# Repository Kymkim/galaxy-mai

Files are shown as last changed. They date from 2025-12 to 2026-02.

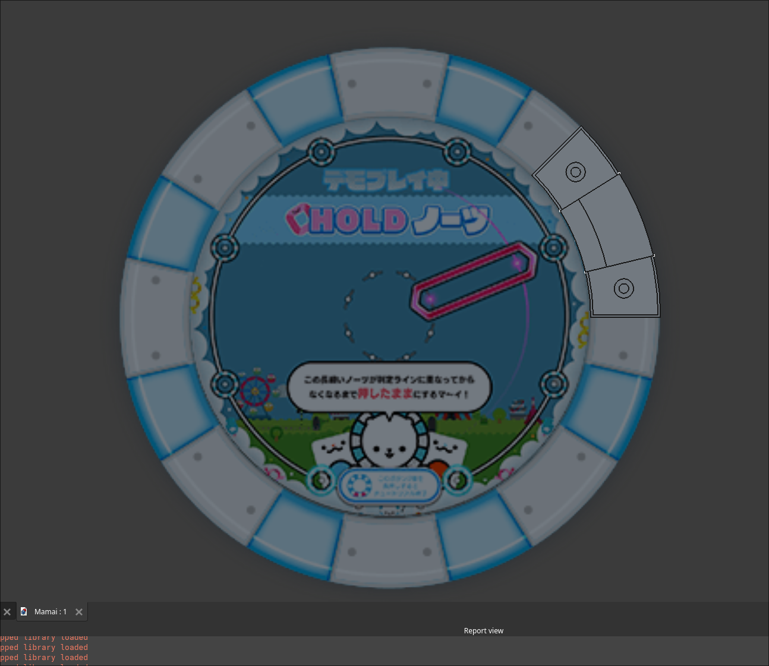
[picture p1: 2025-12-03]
Images/swappy-20251202_193037.png

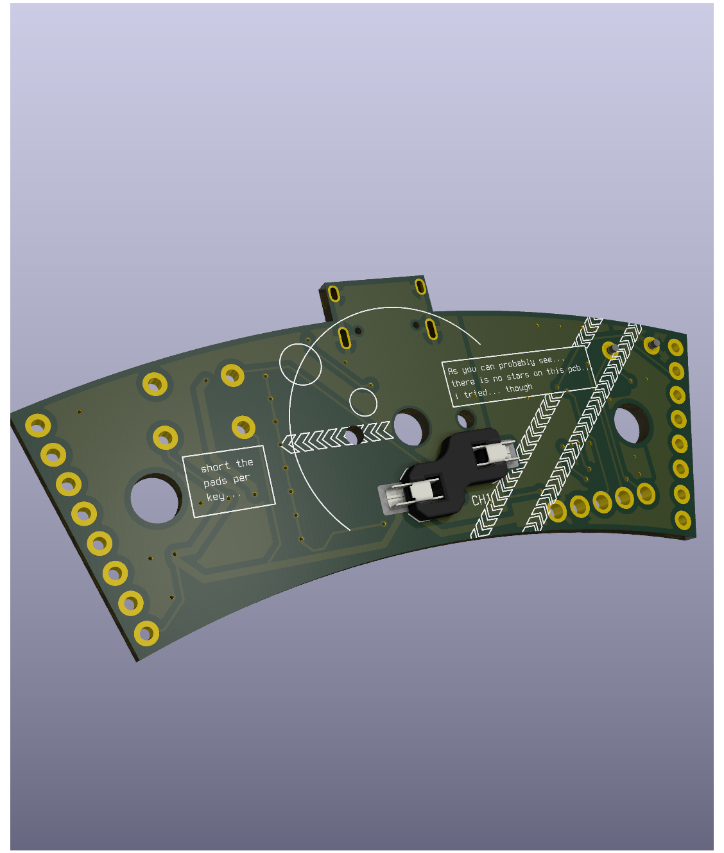
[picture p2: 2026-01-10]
pcb/ss1proto.png

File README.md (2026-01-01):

# galaxy-mai

This project aims to create a AstroDx controller for the Samsung Galaxy Tab

Cooking in progress! Here are some devlogs!

## 01/01/2026: My 3D printer is back!
Few weeks ago I broke my printer so I had to postpone this project for some weeks. I got a new one now so I should be able to hop back into action. Right now I'm in the process of designining the case. Since the design is pretty much constraied by size, I had to draft the case first to get a better idea on how much space I can have once I start putting down the parts in. 

I'm thinking of creating a PCB for this design and some Khail hotswap sockets. They are easy enough to source and should be low profile enough so it looks somewhat proportional to the actual cab. Yes the PCB of course will add up to the overall cost if someone needs to build this instead of just using generic Omron switches - but my reasoning to this is that I want this to be as compact and integrated as possible. 

The schematic and the code of this project is very basic and pretty much just a simple keyboard hid. I have bunch of codes that I have made prior to this project that should let me just reuse the same code and call it the day.

Anyways, I'll keep working on the case and hopefully get something finished and done in one or two weeks

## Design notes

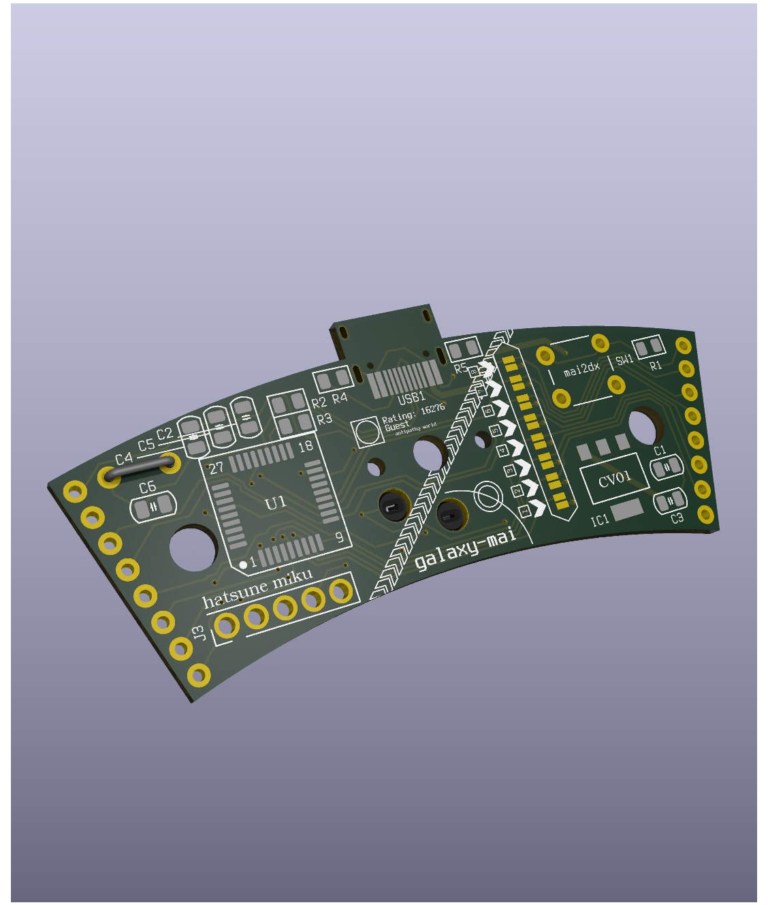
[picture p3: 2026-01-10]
pcb/ss2proto.png

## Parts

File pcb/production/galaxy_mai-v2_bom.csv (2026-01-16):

Designator | Footprint | Quantity | Value | LCSC Part #
C1 | 0805 | 1 | 10uF
C2, C4, C5, C6 | 0805 | 4 | 100uF
C3 | 0805 | 1 | 100nF
CH1 | SW_Hotswap_Kailh_Choc_V1V2 | 1 | choc_v2_SW_HS
IC1 | SOT223 | 1 | LD1117-3.3V-SOT223
JMP_BTN1, JMP_BTN2, JMP_BTN3, JMP_BTN4, JMP_BTN5, JMP_BTN6, JMP_BTN7, JMP_BTN8 | Jumper_2_NO_NoSilk | 8 | ~
R1 | 0805 | 1 | 10k
R2, R3 | 0805 | 2 | 22
R4, R5 | 0805 | 2 | 5.1k
STM32F402K6 | LQFP-32_7x7mm_P0.8mm | 1 | ~
SW1 | SW_PUSH_6mm | 1 | Push_Button
USB1 | HRO-TYPE-C-31-M-12-HandSoldering | 1 | HRO-TYPE-C-31-M-12

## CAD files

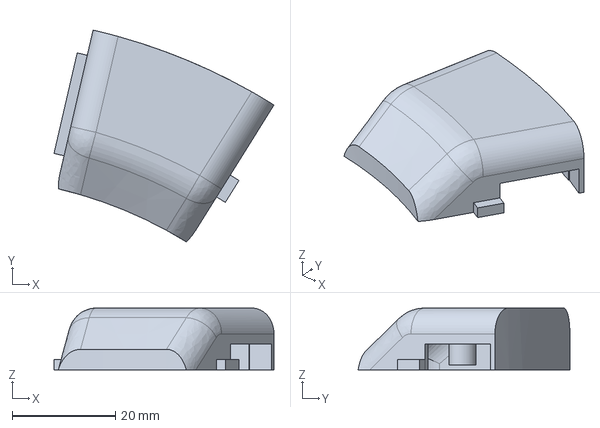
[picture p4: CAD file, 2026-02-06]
3D Parts/Mamai.FCStd
42.6 x 41.1 x 12.0 mm

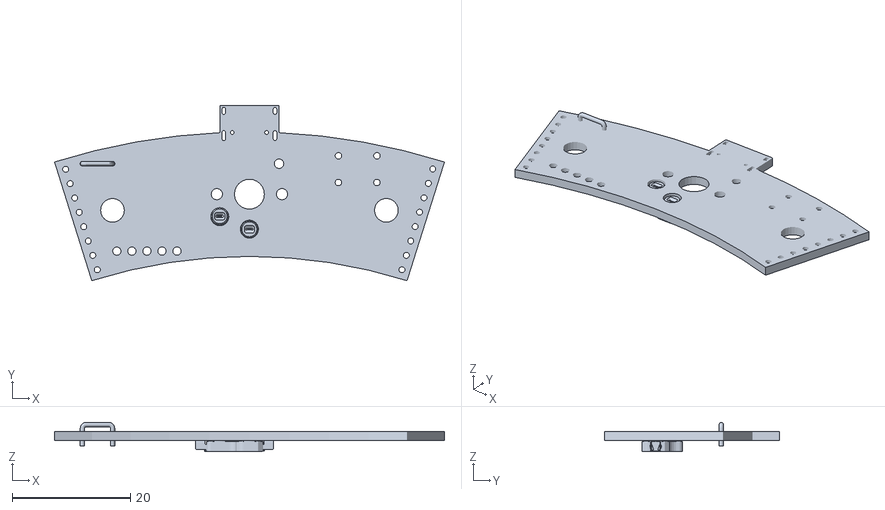
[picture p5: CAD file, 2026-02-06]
pcb/pcb.stl
65.8 x 29.6 x 4.94

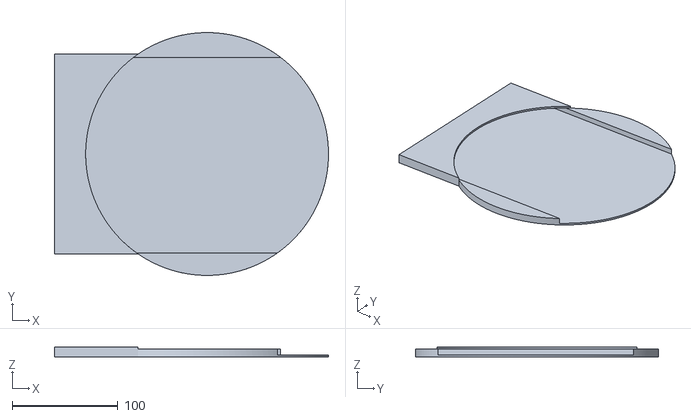
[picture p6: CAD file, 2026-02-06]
3D Parts/Mamai-Case.stl
259.5 x 230.0 x 9.70

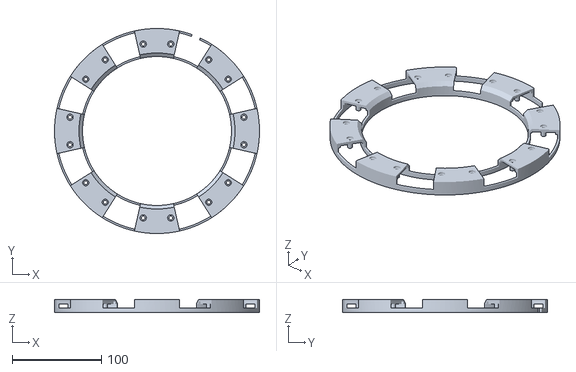
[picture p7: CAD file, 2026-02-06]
3D Parts/Mamai-CaseC.stl
230.0 x 230.0 x 15.0

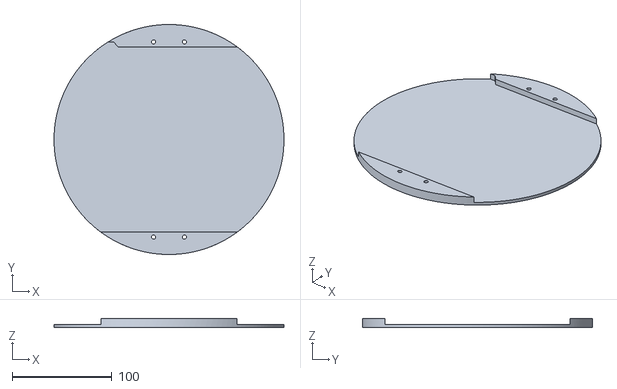
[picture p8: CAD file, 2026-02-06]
3D Parts/Mamai-CaseA.stl
230.0 x 230.0 x 8.70

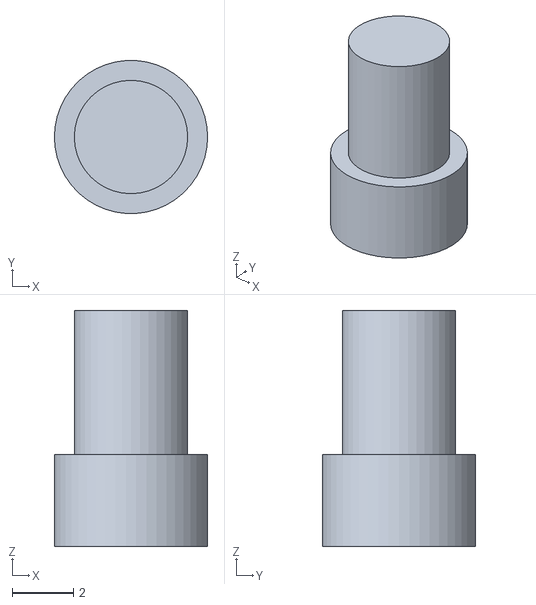
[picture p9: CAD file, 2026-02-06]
3D Parts/Mamai-TestingLockingPin.stl
5.00 x 4.99 x 7.70

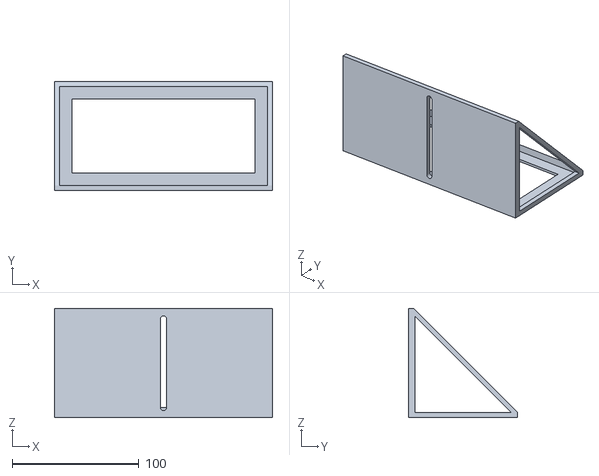
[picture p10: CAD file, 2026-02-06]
3D Parts/Unnamed-Body.stl
172.0 x 86.0 x 86.0

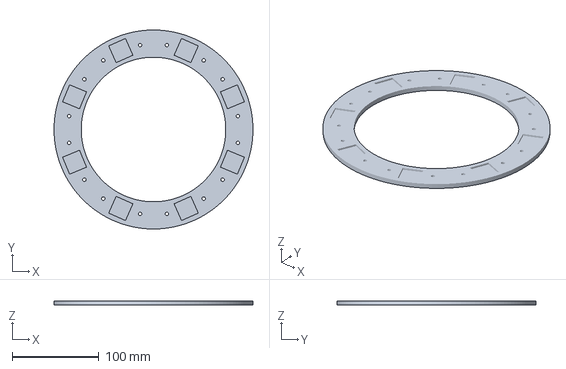
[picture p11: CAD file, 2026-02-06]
3D Parts/Mamai-CaseB.3mf
230.0 x 229.9 x 5.00 mm

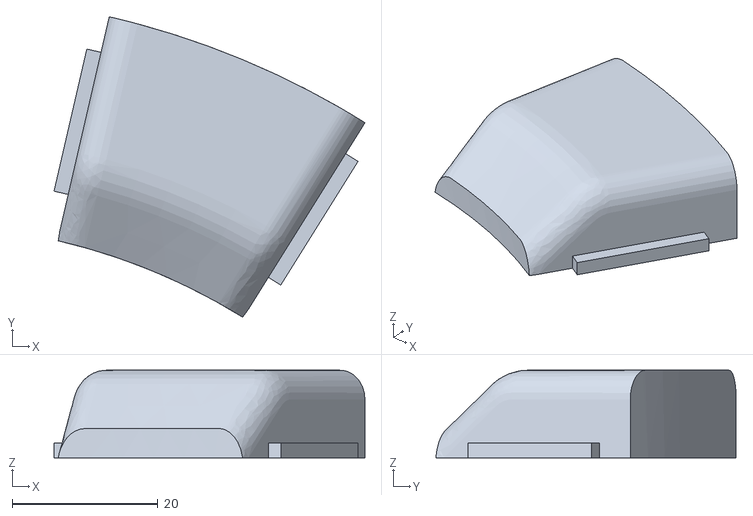
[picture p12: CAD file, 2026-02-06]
3D Parts/Mamai-Button.stl
42.6 x 41.2 x 12.0

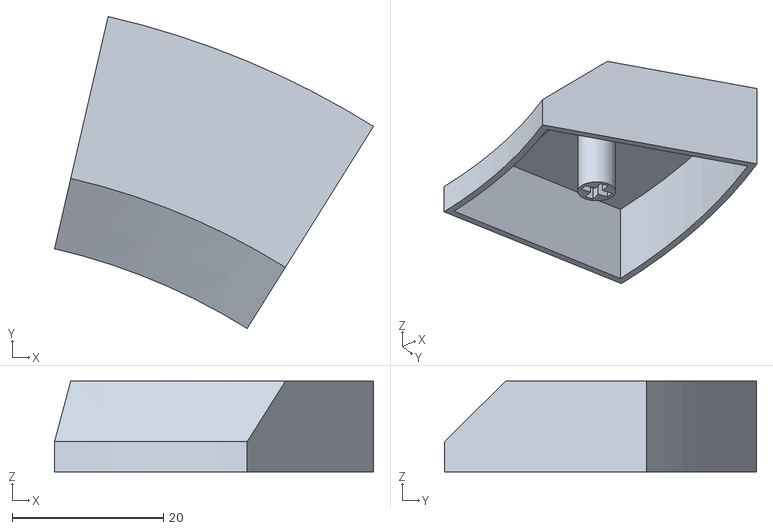
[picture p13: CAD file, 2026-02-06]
3D Parts/Mamai-ButtonPad007.stl
42.2 x 41.2 x 12.0

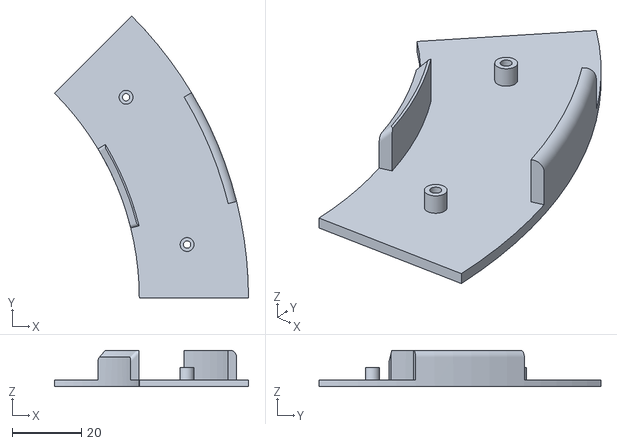
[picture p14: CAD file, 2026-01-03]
3D Parts/Mamai-Body.stl
56.0 x 81.3 x 10.5

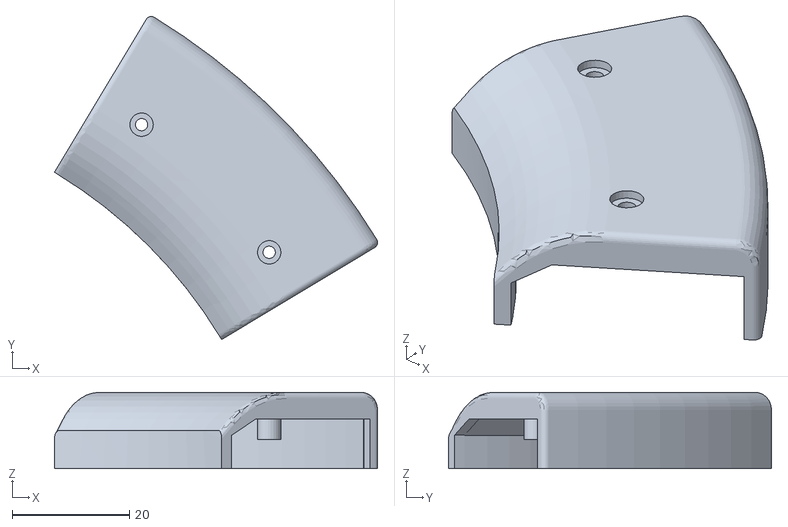
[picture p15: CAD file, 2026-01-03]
3D Parts/Mamai-Joiner.stl
55.2 x 55.2 x 13.0

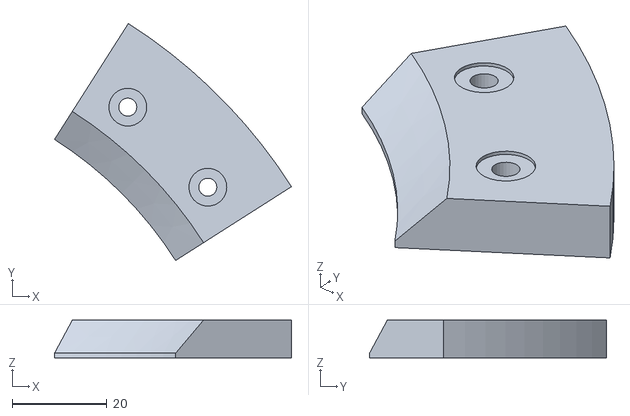
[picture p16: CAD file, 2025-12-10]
3D Parts/Mamai-Body002.stl
50.0 x 50.0 x 8.00

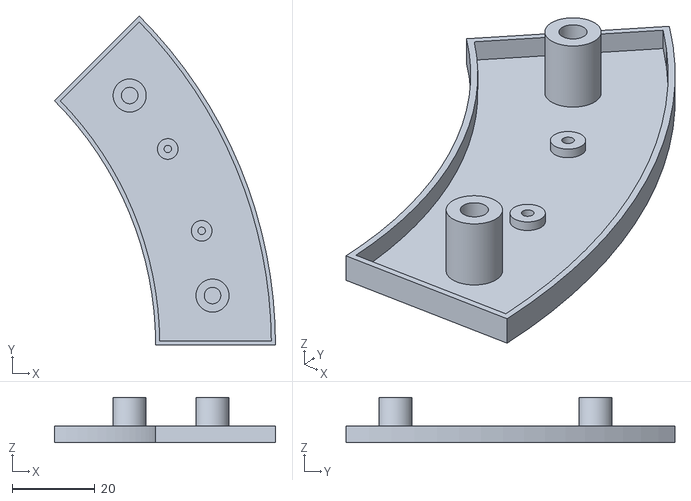
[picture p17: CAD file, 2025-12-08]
3D Parts/baseplate.stl
53.5 x 79.6 x 11.0

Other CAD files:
3D Parts/Mamai-ButtonHoled.stl
3D Parts/Mamai-CaseB.stl
3D Parts/Mamai.3mf
3D Parts/Mamai.stl

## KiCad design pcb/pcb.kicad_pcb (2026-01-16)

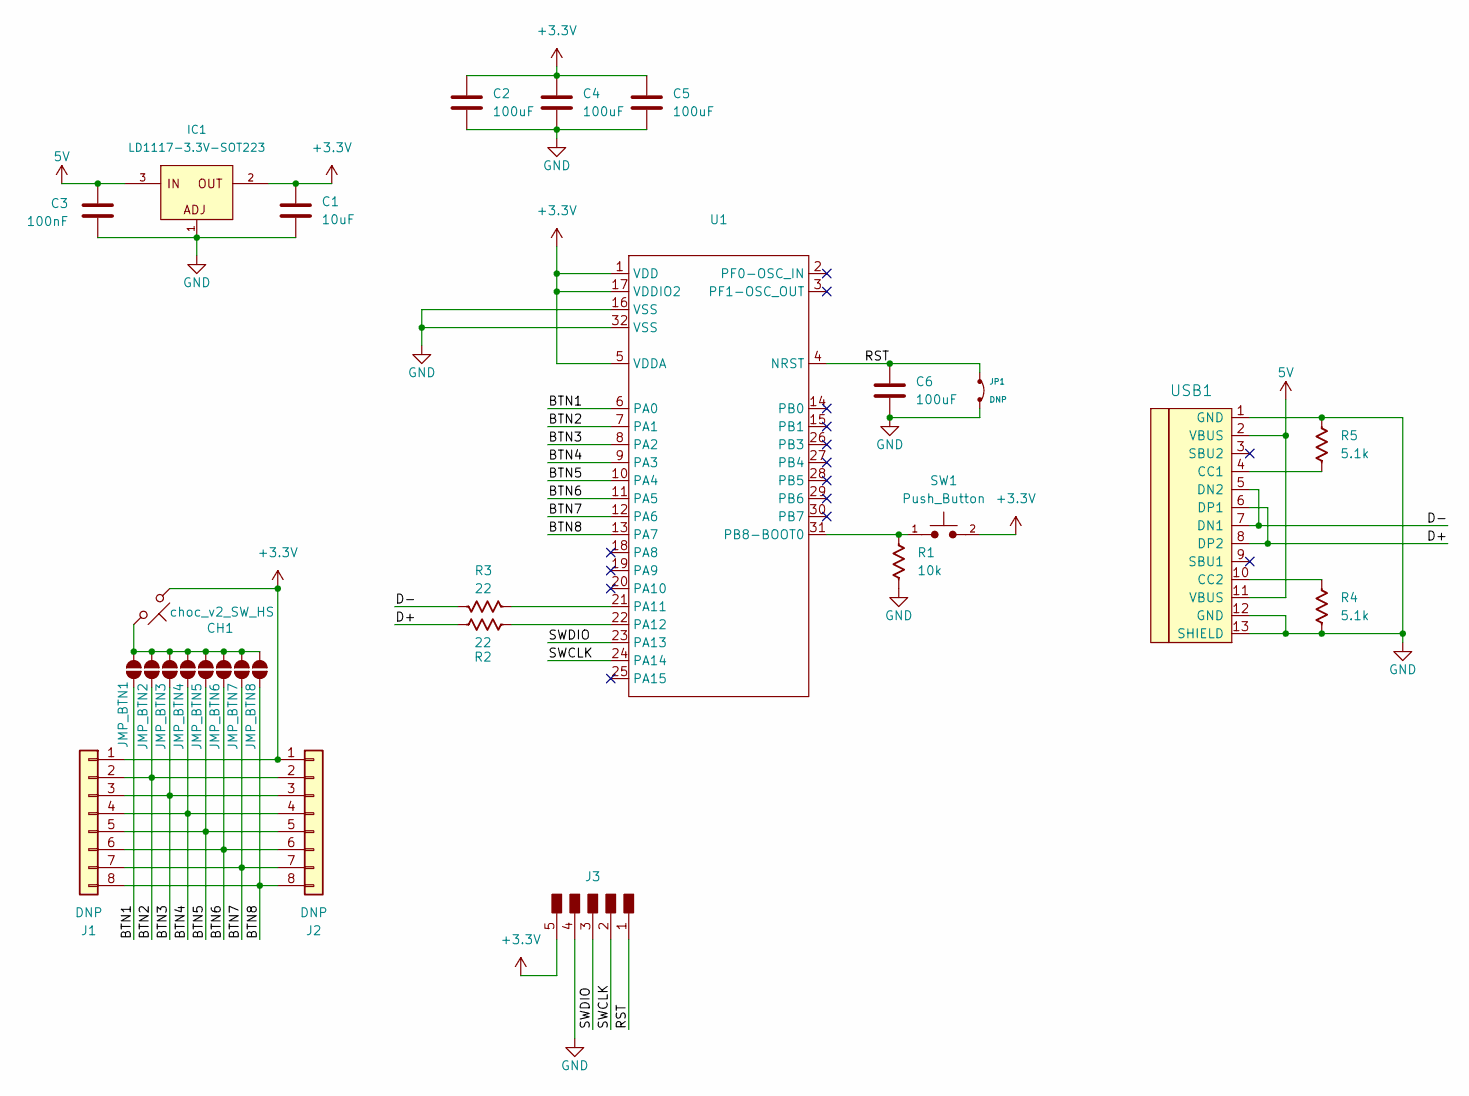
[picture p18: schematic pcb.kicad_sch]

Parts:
C1: 10uF; C_0805_2012Metric
C2, C4, C5, C6: 100uF; C_0805_2012Metric
C3: 100nF; C_0805_2012Metric
CH1: choc_v2_SW_HS; SW_Hotswap_Kailh_Choc_V1V2
IC1: LD1117-3.3V-SOT223; SOT223; Part Number LD1117S33CTR
J1, J2: DNP; 1x08_P2.54mm
J3: DNP; PinHeader_01x05_P2.54mm_Vertical_THT_D1.4mm
JMP_BTN1, JMP_BTN2, JMP_BTN3, JMP_BTN4, JMP_BTN5, JMP_BTN6, JMP_BTN7, JMP_BTN8: Jumper_2_NO_NoSilk
JP1: DNP; JUP_P5.08mm
R1: 10k; R_0805_2012Metric
R2, R3: 22; R_0805_2012Metric
R4, R5: 5.1k; R_0805_2012Metric
SW1: Push_Button; SW_PUSH_6mm
U1: LQFP-32_7x7mm_P0.8mm
USB1: HRO-TYPE-C-31-M-12; HRO-TYPE-C-31-M-12-HandSoldering

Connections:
5V: C3.1, IC1.3 (IN), USB1.2 (VBUS), USB1.11 (VBUS)
+3.3V: C1.2, C2.2, C4.2, C5.2, CH1.2, IC1.2 (OUT), J1.1, J2.1, J3.5, SW1.2, U1.1 (VDD), U1.5 (VDDA), U1.17 (VDDIO2); also elsewhere on the board
/BTN1: JMP_BTN1.2 (B), U1.6 (PA0); also elsewhere on the board
/BTN2: J1.2, J2.2, JMP_BTN2.1 (A), U1.7 (PA1); also elsewhere on the board
/BTN3: J1.3, J2.3, JMP_BTN3.1 (A), U1.8 (PA2); also elsewhere on the board
/BTN4: J1.4, J2.4, JMP_BTN4.1 (A), U1.9 (PA3); also elsewhere on the board
/BTN5: J1.5, J2.5, JMP_BTN5.1 (A), U1.10 (PA4); also elsewhere on the board
/BTN6: J1.6, J2.6, JMP_BTN6.1 (A), U1.11 (PA5); also elsewhere on the board
/BTN7: J1.7, J2.7, JMP_BTN7.1 (A), U1.12 (PA6); also elsewhere on the board
/BTN8: J1.8, J2.8, JMP_BTN8.1 (A), U1.13 (PA7); also elsewhere on the board
/D+: R2.1, USB1.6 (DP1), USB1.8 (DP2)
/D-: R3.1, USB1.5 (DN2), USB1.7 (DN1)
/RST: C6.2, J3.1, JP1.1, U1.4 (NRST); also elsewhere on the board
/SWCLK: J3.2, U1.24 (PA14); also elsewhere on the board
/SWDIO: J3.3, U1.23 (PA13); also elsewhere on the board
GND: C1.1, C2.1, C3.2, C4.1, C5.1, C6.1, IC1.1 (ADJ), J3.4, JP1.2, R1.1, R4.2, R5.1, U1.16 (VSS), U1.32 (VSS), USB1.1 (GND), USB1.12 (GND), USB1.13 (SHIELD); also elsewhere on the board
unnamed: CH1.1, JMP_BTN1.1 (A), JMP_BTN2.2 (B), JMP_BTN3.2 (B), JMP_BTN4.2 (B), JMP_BTN5.2 (B), JMP_BTN6.2 (B), JMP_BTN7.2 (B), JMP_BTN8.2 (B)
unnamed 17: R3.2, U1.21 (PA11); also elsewhere on the board
unnamed 18: R2.2, U1.22 (PA12); also elsewhere on the board
unnamed 19: R1.2, SW1.1, U1.31 (PB8-BOOT0); also elsewhere on the board
unnamed: R5.2, USB1.4 (CC1)
unnamed: R4.1, USB1.10 (CC2)

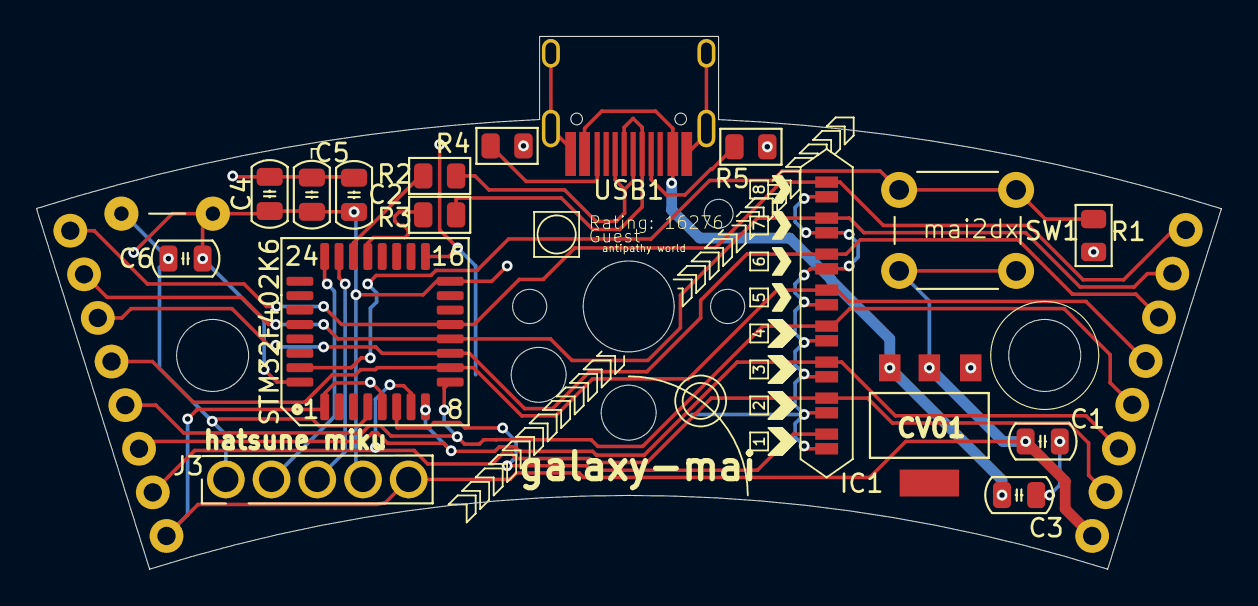
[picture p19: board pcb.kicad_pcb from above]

Board: 2 copper layers, 65.8 x 29.6 mm, 28 parts (0 on the bottom side), 22 nets.

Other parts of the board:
STM32F402K6: LQFP-32_7x7mm_P0.8mm

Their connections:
+3.3V: STM32F402K6.1 (VDD), STM32F402K6.5 (VDDA), STM32F402K6.17 (VDDIO2); also elsewhere on the board
/BTN1: STM32F402K6.6 (PA0); also elsewhere on the board
/BTN2: STM32F402K6.7 (PA1); also elsewhere on the board
/BTN3: STM32F402K6.8 (PA2); also elsewhere on the board
/BTN4: STM32F402K6.9 (PA3); also elsewhere on the board
/BTN5: STM32F402K6.10 (PA4); also elsewhere on the board
/BTN6: STM32F402K6.11 (PA5); also elsewhere on the board
/BTN7: STM32F402K6.12 (PA6); also elsewhere on the board
/BTN8: STM32F402K6.13 (PA7); also elsewhere on the board
/RST: STM32F402K6.4 (NRST); also elsewhere on the board
/SWCLK: STM32F402K6.24 (PA14); also elsewhere on the board
/SWDIO: STM32F402K6.23 (PA13); also elsewhere on the board
GND: STM32F402K6.16 (VSS), STM32F402K6.32 (VSS); also elsewhere on the board
unnamed 17: STM32F402K6.21 (PA11); also elsewhere on the board
unnamed 18: STM32F402K6.22 (PA12); also elsewhere on the board
unnamed 19: STM32F402K6.31 (PB8-BOOT0); also elsewhere on the board

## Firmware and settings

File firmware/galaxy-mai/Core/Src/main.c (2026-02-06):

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
/* Includes ------------------------------------------------------------------*/
#include "main.h"
#include "usb_device.h"
#include "gpio.h"

/* USER CODE BEGIN Includes */
#include "usbd_hid.h"
/* USER CODE END Includes */

/* USER CODE BEGIN PTD */
typedef struct {
  GPIO_TypeDef* port;
  uint16_t pin;
} GPIO_PinPortDef;

typedef struct {
    uint8_t MODIFIER;       // Modifier keys (Ctrl, Shift, Alt, Win)
    uint8_t RESERVED;       // Always 0
    uint8_t KEYPRESS[12];   // Up to 12 keycodes
} __attribute__((packed)) USBHID_ReportDef;

/* USER CODE END PTD */


/* USER CODE BEGIN PV */
uint8_t KEYCODE[8] = {0x1A, 0x08, 0x07, 0x06, 0x1B, 0x1D, 0x04, 0x14};
USBHID_ReportDef REPORT = {0, 0, {0}};
extern USBD_HandleTypeDef hUsbDeviceFS;
/* USER CODE END PV */

void SystemClock_Config(void);
/* USER CODE BEGIN PFP */
void addUSBReport(uint8_t usageID);
/* USER CODE END PFP */

/**
  * @brief  The application entry point.
  * @retval int
  */
int main(void)
{

  /* MCU Configuration--------------------------------------------------------*/

  /* Reset of all peripherals, Initializes the Flash interface and the Systick. */
  HAL_Init();

  /* Configure the system clock */
  SystemClock_Config();

  /* Initialize all configured peripherals */
  MX_GPIO_Init();
  MX_USB_DEVICE_Init();
  /* Infinite loop */
  /* USER CODE BEGIN WHILE */
  while (1)
  {
    /* USER CODE END WHILE */

    /* USER CODE BEGIN 3 */
'''
    addUSBReport(0x1A);''

    // Only send i'f''''''''''''''''''''''' USB is ready
    USBD_HID_SendReport(&hUsbDeviceFS, (uint8_t*)&REPORT, sizeof(REPORT));

    HAL_Delay(10); 
  }
6  /* USER CODE END 3 */
}

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
/* USER CODE BEGIN 4 */
void addUSBReport(uint8_t usageID){
    // Modifier keys (0xE0–0xE7)
    if (usageID >= 0xE0 && usageID <= 0xE7) {
        REPORT.KEYPRESS[0] |= (1 << (usageID - 0xE0));
        return;
    }

    // Normal keys (0x04–0x63)
    if (usageID < 0x04 || usageID > 0x63) return;
    uint16_t bit_index = usageID - 0x04;
    uint8_t byte_index = 2 + (bit_index / 8); // start at REPORT.KEYPRESS[2]
    uint8_t bit_offset = bit_index % 8;
    REPORT.KEYPRESS[byte_index] |= (1 << bit_offset);
}

/* USER CODE END 4 */
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


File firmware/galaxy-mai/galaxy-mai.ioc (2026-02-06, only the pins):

Mcu.UserName=STM32F042K6Tx
PA0.GPIO_Label=BTN1
PA0.Signal=GPIO_Input
PA1.GPIO_Label=BTN2
PA1.Signal=GPIO_Input
PA11.Signal=USB_DM
PA12.Signal=USB_DP
PA13.Signal=SYS_SWDIO
PA14.Signal=SYS_SWCLK
PA2.GPIO_Label=BTN3
PA2.Signal=GPIO_Input
PA3.GPIO_Label=BTN4
PA3.Signal=GPIO_Input
PA4.GPIO_Label=BTN5
PA4.Signal=GPIO_Input
PA5.GPIO_Label=BTN6
PA5.Signal=GPIO_Input
PA6.GPIO_Label=BTN7
PA6.Signal=GPIO_Input
PA7.GPIO_Label=BTN8
PA7.Signal=GPIO_Input

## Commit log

2025-12-03 worked on buttons design
    [Mamai-Button.stl, Mamai.FCStd, pcb.kicad_sch]
2025-12-08 topshefl work
    [Mamai.FCStd, PCBWay_bom.csv, PCBWay_positions.csv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]
2025-12-10 top plate addition
    [Mamai-Body.stl, Mamai-Body002.stl, Mamai-Button.stl]
2025-12-27 Update README with hiatus note
    Added hiatus note about 3D printer issue.
2026-01-01 revised 3d model
    [Mamai.FCStd]
2026-01-03 pcb stuff
    [Mamai-Body.stl, Mamai-Button.stl, Mamai-Joiner.stl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]
2026-01-06 some schematic changes
    [Mamai.FCStd, pcb.kicad_pcb, pcb.kicad_sch]
2026-01-07 making a curved pcb was a mistake, why did i angled this
    [freerouting.dsn, pcb.kicad_pcb, pcb.kicad_sch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]
2026-01-08 pcb revise
    [pcb.kicad_pcb]
2026-01-09 pcb drc factoring pending
    [freerouting.dsn, pcb.kicad_pcb, pcb.kicad_sch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]
2026-01-10 drc resolved pcb ordered
    [pcb.kicad_pcb, pcb.kicad_sch, pcb.stl]
2026-01-16 revised pcb because im a dummy and put the wrong mcu size
    [galaxy_mai-v2_bom.csv, galaxy_mai-v2_designators.csv, galaxy_mai-v2_positions.csv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]
2026-02-06 lots of messages
    [Mamai-Button.stl, Mamai-ButtonHoled.stl, Mamai-ButtonPad007.stl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]

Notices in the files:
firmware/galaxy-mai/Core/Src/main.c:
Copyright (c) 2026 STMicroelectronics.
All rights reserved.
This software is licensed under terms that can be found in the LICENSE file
